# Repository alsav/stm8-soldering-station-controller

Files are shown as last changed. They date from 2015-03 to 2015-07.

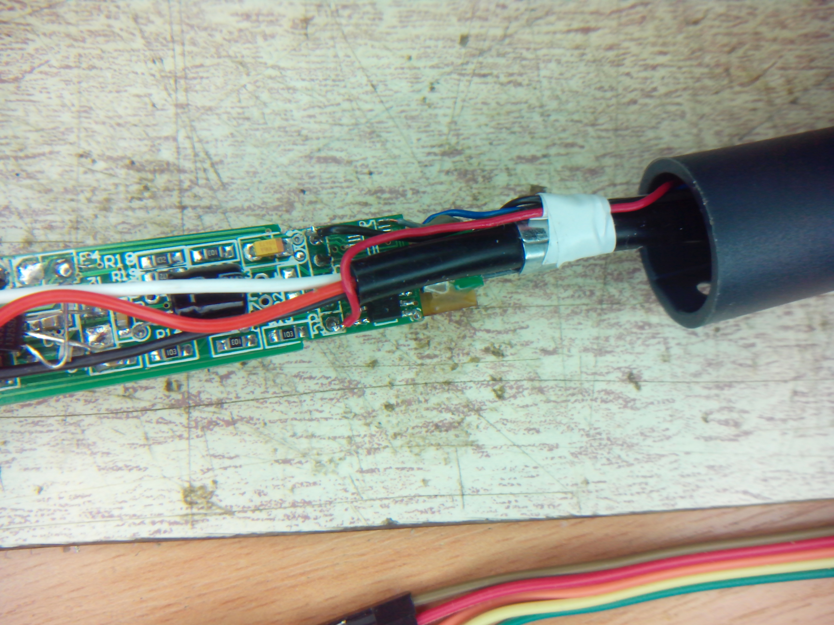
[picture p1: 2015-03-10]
IMG3.jpg

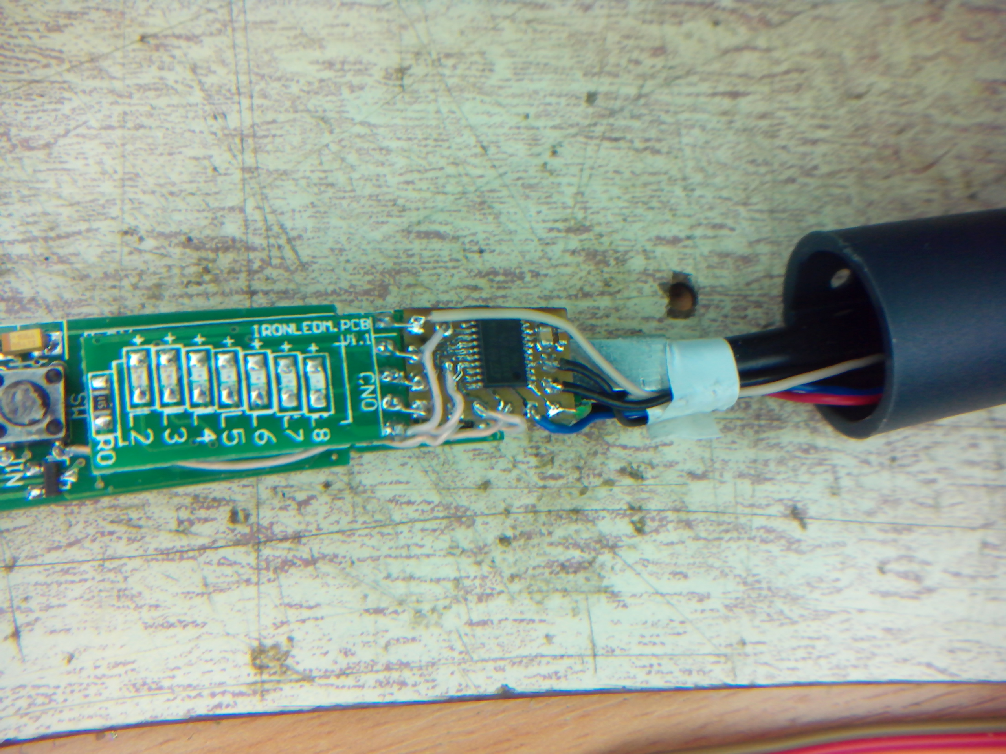
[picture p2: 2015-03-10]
IMG2.jpg

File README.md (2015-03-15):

Tomizawa FZ-880B soldering station controller open-source firmware
==================================================================

Цель данного проекта - реанимация умершего чуда китайской инженерной мысли: паяльника с терморегуляцией Tomizawa FZ-880 и его клонов.
Т.к. схемотехника агрегата мягко говоря не очень, возможно еще кому-то пригодится...

Итак, самое слабое место - схема питания МК. Если паяльник перестал подавать признаки жизни и при включении в розетку монотонно горят один илн несколько светодиодов - ваш случай.

Для восстановления потребуется:
1. Прокачать до второго уровня или выше схему питания микроконтроллера (см.фото).
2. Изготовить методом лута печатку под новый МК STM8S003F3P6, прикупив последний где-нибудь тут: http://www.ebay.com/sch/i.html?&_nkw=stm8s003f3
3. Прошить МК и установить плату вместо стокового контроллера на свободное место.

Файлы:
1. firmware_vX.X.hex - сама прошивка.
2. ctrl-brd_reduced-F_Cu.ps - шаблон для изготовления платы (формат post-script).
3. Все остальное - если будете заморачиваться с допилкой под сови нужды и повторной сборкой.

Для компиляции использовался sdcc 3.4.3 #9179 под linux (ubuntu 14.04).
Для шитья - Versaloon (в проекте) или более доступное средство: ST_Link V2.

Features:
1. Термостабилизация ПИД-регулятором. Точность 5-10С.
2. Предварительный прогрев до температуры режима n+1 для сокращения времени нагрева жала.
3. Индикация выхода на рабочий температурный режим миганием светодиода.
4. Отключение паяла длинным нажатием.

TODO (если будет не лень):
1. Режим калибровки: точная подстройка температуры с сохранением в eeprom.

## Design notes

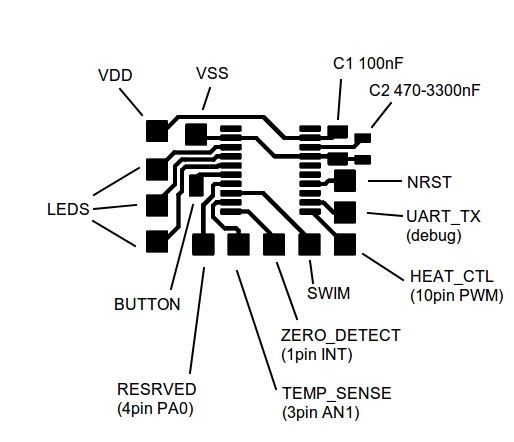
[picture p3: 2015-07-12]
board_pinout.jpg

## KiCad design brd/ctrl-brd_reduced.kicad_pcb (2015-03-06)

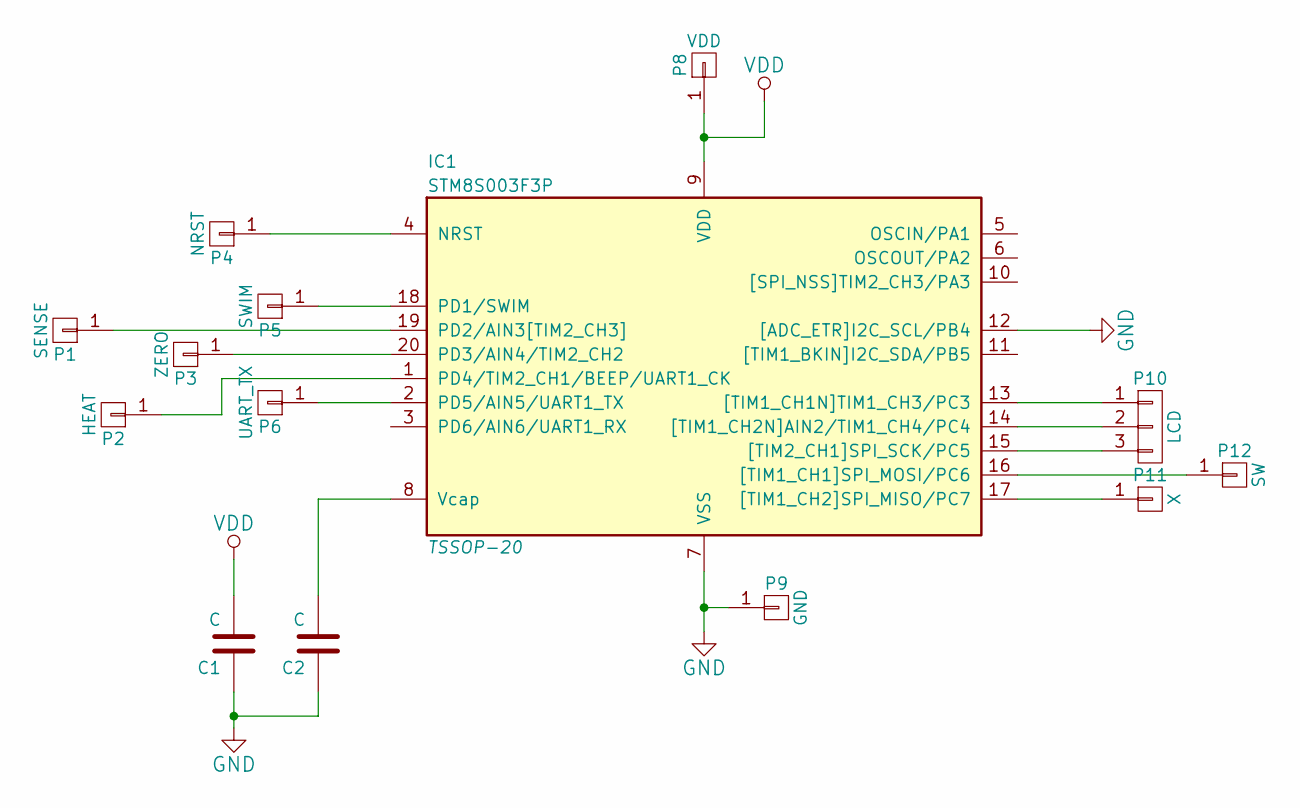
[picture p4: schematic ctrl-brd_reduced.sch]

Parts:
C1, C2: C
IC1: STM8S003F3P; TSSOP-20
P1: SENSE
P2: HEAT
P3: ZERO
P4: NRST
P5: SWIM
P6: UART_TX
P8: VDD
P9: GND
P10: LCD
P11: X
P12: SW

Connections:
GND: C1.1, C2.1, IC1.7 (VSS), IC1.12 ([ADC_ETR]I2C_SCL/PB4), P9.1
unnamed: IC1.15 ([TIM2_CH1]SPI_SCK/PC5), P10.3
unnamed: IC1.14 ([TIM1_CH2N]AIN2/TIM1_CH4/PC4), P10.2
unnamed: IC1.13 ([TIM1_CH1N]TIM1_CH3/PC3), P10.1
unnamed: IC1.18 (PD1/SWIM), P5.1
unnamed: C2.2, IC1.8 (Vcap)
unnamed: IC1.4 (NRST), P4.1
unnamed: IC1.1 (PD4/TIM2_CH1/BEEP/UART1_CK), P2.1
unnamed: IC1.19 (PD2/AIN3[TIM2_CH3]), P1.1
unnamed: IC1.16 ([TIM1_CH1]SPI_MOSI/PC6), P12.1
unnamed: IC1.17 ([TIM1_CH2]SPI_MISO/PC7), P11.1
unnamed: IC1.20 (PD3/AIN4/TIM2_CH2), P3.1
unnamed: IC1.2 (PD5/AIN5/UART1_TX), P6.1
VDD: C1.2, IC1.9 (VDD), P8.1

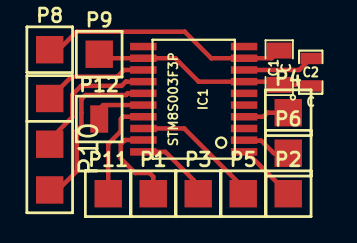
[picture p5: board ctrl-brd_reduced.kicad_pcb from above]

Board: 2 copper layers, 14 parts (0 on the bottom side), 14 nets.

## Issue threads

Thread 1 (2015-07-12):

Доработка документации

evilslon, 2015-07-12:
Я, как и Вы, столкнулся с тем, что мой паяльник Tomizawa FZ-880C умер от скачка сетевого напряжения. В результате проверки, я диагностировал КЗ в процессоре 46R01, поэтому Ваш проект мне показался очень интересен и я решил повторить Ваш опыт. Но, судя по всему, Вы не предполагали, что кто-то на это решится и оставили документацию в недоработанном состоянии. Схемы подключения создаваемой платы нет, а посему многое непонятно. С какого, например, вывода STM8 берётся PWM сигнал, идущий на 10 вывод выпаянной микросхемы (а затем на R11 и базу P2)? Укажите, пожалуйста, ёмкость конденсатора C2 (подключен к выводу Vcap) и C1 (фильтр питания) на Вашей платке. Расскажите поподробнее про доработку системы питания микроконтроллера. Если не сложно, напишите свой email для связи. Заранее спасибо!

alsav, 2015-07-12:
Приветствую!

Добавил в проект схему подключения платы (файл board_pinout.jpg). Номиналы конденсаторов указал там же, все взяты из даташита на МК. HEAT_CTL, ZERO_DETECT и TEMP_SENSE подключаются к 46R01, в скобках указаны номера выводов. SWIM и NRST - для прошивки МК. UART_TX и RESERVED в рабочем варианте не используются. Остальное думаю понятно.

Про доработку схемы питания немного есть в IMG1.jpg. Изначально схема состояла из конденсатора C2, диодов D3 и D4 и стабилитрона Z1 скорее всего на 3.3 или 5В. Под выводами R24 оказалась дорожка. Таким образом после C2 ток ничем не ограничивался, что вызвало пробой Z1 и U1. Чтобы исправить ситуацию, удалил дорожку под R24, увеличил сопротивление до 150Ом. Z1 заменил на TL431A с резисторным делителем на 3.3В. Номиналы резисторов 10 и 30КОм, сделаны навесным монтажом. IMG4.jpg - что получилось в результате.
Если что-то будет не понятно - спрашивайте al.sadakov<собачка>gmail.com.
На всякий случай предупреждаю: т.к. схема питания логики не имеет гальванической развязки, при прошивке МК ОБЯЗАТЕЛЬНО обключать паяльник от сети! Питание при прошивке берется с программатора.
Удачи!

Closed 2016-08-03.

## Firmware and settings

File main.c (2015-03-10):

/*
Copyright (C) 2015 Alexander Sadakov <al.sadakov_dog_gmail.com>

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
This program is distributed in the hope that it will be useful,
but WITHOUT ANY WARRANTY; without even the implied warranty of
MERCHANTABILITY or FITNESS FOR A PARTICULAR PURPOSE.  See the
GNU General Public License for more details.
*/

#include "main.h"



extern volatile uint8_t flags;
extern uint8_t temp_lvl;
extern volatile uint8_t heat_counter;
extern int8_t heat_cycles;

extern uint8_t txbuf[UART_BUF_SIZE];	//for debug



int main( void )
{
    uint8_t i=0;

    disableInterrupts();

    HW_Init();
    UART_Config();

    enableInterrupts();


    flags=0;
    temp_lvl=0;
    LEDS_OFF;

    heat_counter = HEAT_IDLE_CYCLES;
    heat_cycles=30;


    UART_SendStr("OK!\r\n");


    mainLoop();

    return 0;

}

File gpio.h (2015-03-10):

//
//ZERO-DETECTION PIN - EXTI RISE/FALL
//
#define ZERO_DETECT_PORT GPIOD
#define ZERO_DETECT_PIN GPIO_PIN_3
//#define ZERO_DETECT_EXTI EXTI_PORT_GPIOD
#define ZERO_DETECT_EXTI_RISE_FALL 0b11000000	//zero-detect-port exti sensitivity (write to CR1)


//
//SWITCH PIN - INPUT
//
#define SWITCH_PORT GPIOC
#define SWITCH_PIN GPIO_PIN_6
//#define SWITCH_EXTI_RISE_FALL 0b00110000	//switch-port exti sensitivity (write to CR1)


//
//LED-PANEL - PUSH-PULL
//
#define LED_GPIO_PORT GPIOC
#define LED_GPIO_PINS GPIO_PIN_3 | GPIO_PIN_4 | GPIO_PIN_5
#define LED_GPIO_MASK  0b11000111

#define LEDS_OFF LED_GPIO_PORT->ODR &= LED_GPIO_MASK;
#define LEDS_SET(val) LED_GPIO_PORT->ODR &= LED_GPIO_MASK; LED_GPIO_PORT->ODR ^= (val<<3);



//
//HEATER - PUSH-PULL
//
#define HEATER_PORT GPIOD
#define HEATER_PIN GPIO_PIN_4

#define HEATER_ON HEATER_PORT->ODR &= ~HEATER_PIN
#define HEATER_OFF HEATER_PORT->ODR |= HEATER_PIN


//
//TEMP SENSOR - ADC
//
#define TEMP_SENS_ADC_CHANNEL ADC1_CHANNEL_3




void GPIO_Config(void);

extern INTERRUPT_HANDLER(EXTI_PORTA_IRQHandler, 3);
extern INTERRUPT_HANDLER(EXTI_PORTB_IRQHandler, 4);
extern INTERRUPT_HANDLER(EXTI_PORTC_IRQHandler, 5);
extern INTERRUPT_HANDLER(EXTI_PORTD_IRQHandler, 6);

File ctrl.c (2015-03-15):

/*
Copyright (C) 2015 Alexander Sadakov <al.sadakov_dog_gmail.com>

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
This program is distributed in the hope that it will be useful,
but WITHOUT ANY WARRANTY; without even the implied warranty of
MERCHANTABILITY or FITNESS FOR A PARTICULAR PURPOSE.  See the
GNU General Public License for more details.
*/
#include "main.h"
//HSI 2MHZ

uint16_t phase_ticks=0;
int16_t temp_error;

uint8_t switch_pressed_timer;

uint8_t temp_lvl;
uint8_t temp_lvl_real;

volatile uint8_t flags;

volatile uint8_t conv_num;
volatile uint16_t conv_result;

volatile uint8_t heat_counter;		//for caluclated heat||idle cycles
int8_t heat_cycles;			//pid regulated value


int8_t pgains[TEMP_LEVELS] = {1,1,1,1,2,2,2,2};
int8_t igains[TEMP_LEVELS] = {1,1,1,2,2,2,4,4};


pid_struct pid = {
    0, 0,		//dstate, istate
    10, 0,		//imax, imin
    50, 0,		//max/min output limits
    1, 1, 0		//p, i, d gains
};

uint16_t temp_adc[TEMP_LEVELS] = { \
    0,			\ //0 OFF
    180,		\ //1 200C
    220,		\ //2 250C
    260,		\ //3 300C
    300,		\ //4 350C
    340,		\ //5 400C
    390,		\ //6 450C
    450			\ //7 480C (MAX)
};


extern uint8_t txbuf[UART_BUF_SIZE];	//for debug


void mainLoop()
{

    while(1) {



	//pid processing and output debug msg
	if (get_flag(FLAG_END_ADC_CONV)) {

	    temp_error = temp_adc[temp_lvl_real] - conv_result;

	    if ( get_flag(FLAG_PREHEAT) && (temp_error<5) ) {			//check if preheat phase completed
		temp_lvl_real = temp_lvl;
		reset_flag(FLAG_PREHEAT);
	    }

	    if ( get_flag(FLAG_BLINK_ON) && ((get_flag(FLAG_PREHEAT))==0) ) {	//BLINK_OFF if temp stabilized
		if ( (temp_error>-5) && (temp_error<5) ) {
		    LEDS_SET(temp_lvl);
		    reset_flag(FLAG_BLINK_ON);
		}
	    }

	    //calculate error for pid
	    temp_error = temp_adc[temp_lvl_real] - conv_result;
	    if (temp_error > 127) 
		temp_error=127;	// for int8_t in pid
	    else if (temp_error<-127)
		temp_error=-127;

	    heat_cycles = update_pid(&pid, (int8_t)(temp_error), conv_result);

	    reset_flag(FLAG_END_ADC_CONV);

//DBG
//	sprintf(txbuf,"%d,%d %d %d %x\r\n",conv_result,(uint16_t)(temp_lvl), (int16_t)heat_cycles, (int16_t)((int8_t)(temp_error)), (uint16_t)(flags));
//	UART_SendStr(txbuf);    //send result to uart
	}


	//zero-detection time-non-critical events processiong
	if (get_flag(FLAG_ZERO_REACHED)) {

	    reset_flag(FLAG_ZERO_REACHED);
	    phase_ticks++;


	    //leds blink
	    if (get_flag(FLAG_BLINK_ON)) {
		if ( (phase_ticks & 0b011111) == 0 ) {
		    LEDS_SET(temp_lvl);
		} else if ( (phase_ticks & 0b100000) == 0 ) {
		    LEDS_SET(0);
		}
	    }


	    //long switch-pressed: pwr-off
	    if (get_flag(FLAG_SWITCH_PRESSED)) {
		switch_pressed_timer++;
//		if ( switch_pressed_timer == 0 ) {
		if ( switch_pressed_timer == 0x90 ) {
		    switch_pressed_timer=0;
		    temp_lvl=0;
		    temp_lvl_real=0;
		    LEDS_SET(0);
		}
	    }

	    //if key is pressed
	    if ( ((SWITCH_PORT->IDR & SWITCH_PIN)==0) && ((get_flag(FLAG_SWITCH_PRESSED))==0) ) {
		set_flag(FLAG_SWITCH_PRESSED);
		switch_pressed_timer=0;
		temp_lvl = (temp_lvl+1) % 8;
		LEDS_SET(temp_lvl);
		set_flag(FLAG_BLINK_ON);
		set_flag(FLAG_PREHEAT);

		pid.pgain=pgains[temp_lvl];
		pid.igain=igains[temp_lvl];

		if ((temp_lvl<7) && (temp_lvl>0)) {
		    temp_lvl_real = temp_lvl+1;
		} else {
		    reset_flag(FLAG_PREHEAT);
		    reset_flag(FLAG_BLINK_ON);
		    temp_lvl_real = temp_lvl;
		}

	    //if key is released (pull-up)
	    } else if ( (SWITCH_PORT->IDR & SWITCH_PIN) && get_flag(FLAG_SWITCH_PRESSED) ) {
		reset_flag(FLAG_SWITCH_PRESSED);
	    }


	}


    } // end while(1)

}






//zero-detection exti handler
INTERRUPT_HANDLER(EXTI_PORTD_IRQHandler, 6)
{

    set_flag(FLAG_ZERO_REACHED);	// for main-loop processing

    //zero-detection event processing
    if ( ZERO_DETECT_PORT->IDR & ZERO_DETECT_PIN ) {
        if ( get_flag(FLAG_END_TEMP_MEASURE) ) {
	    reset_flag(FLAG_END_TEMP_MEASURE);
	    if (heat_cycles) {
		HEATER_ON;
		set_flag(FLAG_HEATER_ENABLED);
		heat_counter = heat_cycles;
	    }
	} else if (heat_counter == 0) {
	    if (get_flag(FLAG_HEATER_ENABLED)) {
		HEATER_OFF;
		reset_flag(FLAG_HEATER_ENABLED);
		heat_counter = HEAT_IDLE_CYCLES; 
	    } 
	} else {
		heat_counter--;
	}
    } else if ( (ZERO_DETECT_PORT->IDR & ZERO_DETECT_PIN)==0 ) {
	if ( (heat_counter == 0) && (!get_flag(FLAG_HEATER_ENABLED)) ) {
	    //start ADC conversion
	    ZERO_DETECT_PORT->CR2 &= ~ZERO_DETECT_PIN;	//disable zero_detect_pin interrupt
	    conv_result=0;
	    conv_num=16;
	    ADC1->CR1 |= ADC1_CR1_ADON;			//start adc conversion
	}
    }

}


//end adc conversion
INTERRUPT_HANDLER(ADC1_IRQHandler, 22)
{
    ADC1->CSR &= ~ADC1_CSR_EOC;			//clear end-of-conversion flag

    conv_result += (ADC1->DRH << 8);		//add conversion to result
    conv_result += ADC1->DRL;

    if (conv_num) {				//if not all adc conversions: wait tim4 and start adc again
	conv_num--;
	TIM4->CR1 |= TIM4_CR1_CEN;		//enable tim4

    } else {					//all conversions finished

	conv_result=conv_result>>4;

	set_flag(FLAG_END_TEMP_MEASURE);
	set_flag(FLAG_END_ADC_CONV);

//	EXTI->CR1 |= (uint8_t)(EXTI_SENSITIVITY_RISE_FALL);	//set EXTI PORTS-sens
	ZERO_DETECT_PORT->CR2 |= ZERO_DETECT_PIN;	//enable zero_detect_pin interrupt
    }

}


//timer interrupt
INTERRUPT_HANDLER(TIM4_UPD_OVF_IRQHandler, 23)
{

    TIM4->SR1 &= ~TIM4_SR1_UIF;	//clear update interrupt flag
    TIM4->CR1 &= ~TIM4_CR1_CEN;	//disable tim4
    ADC1->CR1 |= ADC1_CR1_ADON;	//start next adc conversion

}

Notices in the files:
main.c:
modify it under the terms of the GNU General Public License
